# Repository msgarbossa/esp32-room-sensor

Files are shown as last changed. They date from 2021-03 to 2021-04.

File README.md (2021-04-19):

# ESP32 room temp sensor

## Overview

This ESP32 sensor is setup to wake from deep sleep every 5 minutes, take a sensor reading, send the data to MQTT, and go back to sleep.  Intended for dark rooms, the OLED is only activated for about 10 seconds by tapping the touch sensor on the top.  The number in the lower-right corner is the signal strength.  Update settings in src/config/config.h.

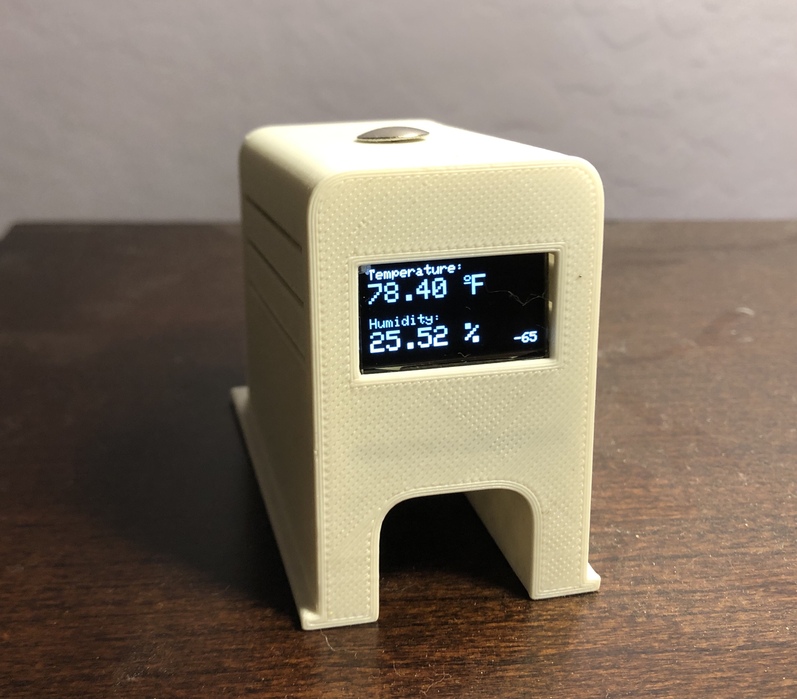
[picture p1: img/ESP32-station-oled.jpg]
project photo


I resized this case to fit the parts I like to use.  The screen is currently just glued in with hot glue.

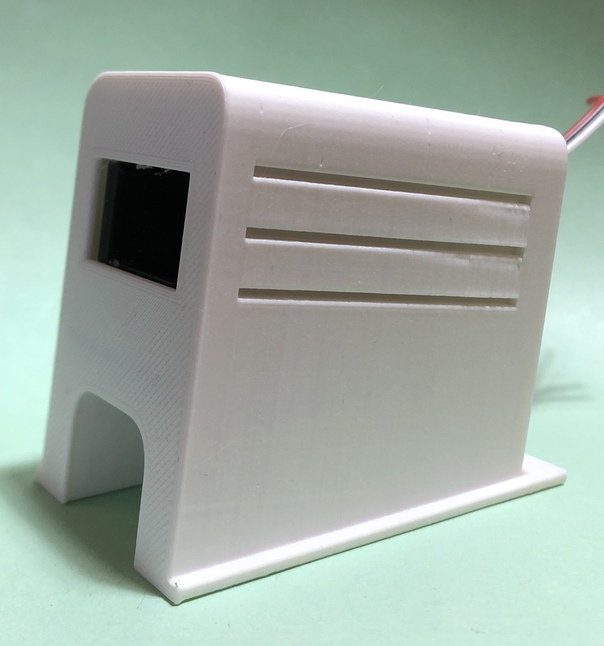
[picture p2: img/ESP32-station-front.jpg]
front


The 30-pin ESP32 board with integrated antenna slides perfectly into the rail.

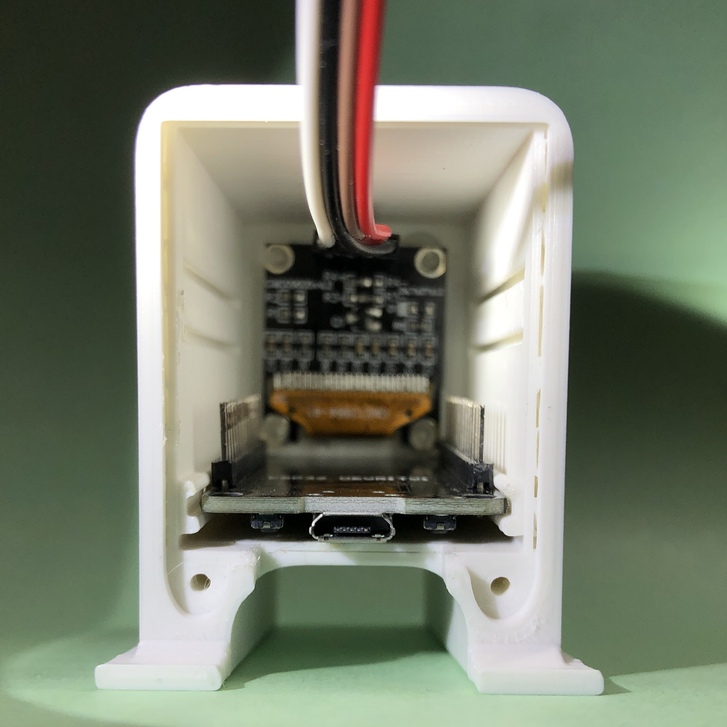
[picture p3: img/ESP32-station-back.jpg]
back


The cover hooks into the top edge and the bottom can stay pressed in.  I didn't need to add screws.  I modified the cover with a small cutout at the top so the BME280 sensor can be external.  I'd like to further tweak the cover to better hold the sensor.

## Parts

- [ESP32 devkit - 30 pin, integrated antenna](https://www.aliexpress.com/item/1005001267643044.html)
- [0.96" OLED - white, I2C](https://www.aliexpress.com/item/32896971385.html)
- [BME280 sensor](https://www.aliexpress.com/item/4001098967210.html)

## Diagram

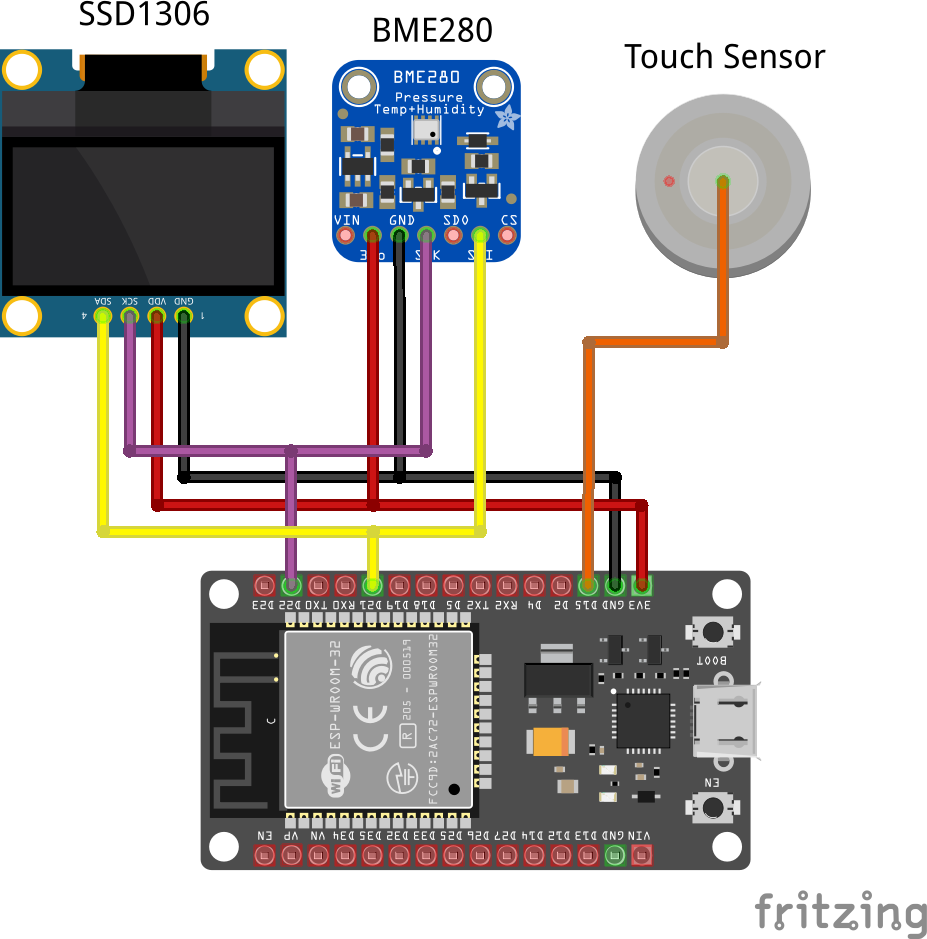
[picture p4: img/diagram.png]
diagram


## Node-RED

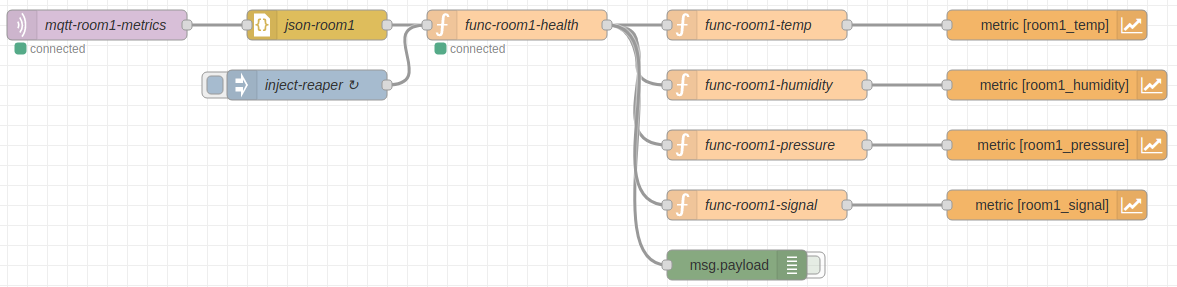
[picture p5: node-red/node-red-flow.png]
Node-RED flow

[JSON for above flow](node-red/flow.json)

The beginning of the flow starts out very simple.  Node-RED listens on the MQTT topic for the sensor.  The messages get converted from JSON to payload objects.

To understand the rest of the flow, it's important to go over how the Prometheus node exporter works in Node-RED.  The orange metric boxes to the right-side of the flow generate the prometheus data shown below at \<node_red_url\>:1880/metrics.

```
# HELP room1_temp room1 temp
# TYPE room1_temp gauge
room1_temp 78

# HELP room1_humidity room1 humidity
# TYPE room1_humidity gauge
room1_humidity 31.32

# HELP room1_pressure room1 pressure
# TYPE room1_pressure gauge
room1_pressure 964.77

# HELP room1_signal room1 signal
# TYPE room1_signal gauge
room1_signal -70
```

The challenge has been dealing with sensors that go offline.  The metric node would not receive an updated value and continue to display an old value.  This would show up in the graphs in Grafana as a flat-line.  There might be a more elegant solution, but what I've done for now is to use an inject node to regularly inject a healthcheck message into the flow.  The healthcheck function node uses node context to store the time of the last valid message that came from MQTT.  When the healthcheck message is injected, the time of the inject message is compared to the time of the last valid message.  If the time difference is greater than the threshold, the healthcheck node's status is set to "offline" and a new message is generated and passed along with the metric values set to zero.  The Grafana graphs are set to only display values greater than zero.

The functions to the left of each of the orange metric nodes simply reformat the payload messages to set the metric values as required for the Promtheus metric nodes.

Below is an example graph in Grafana.

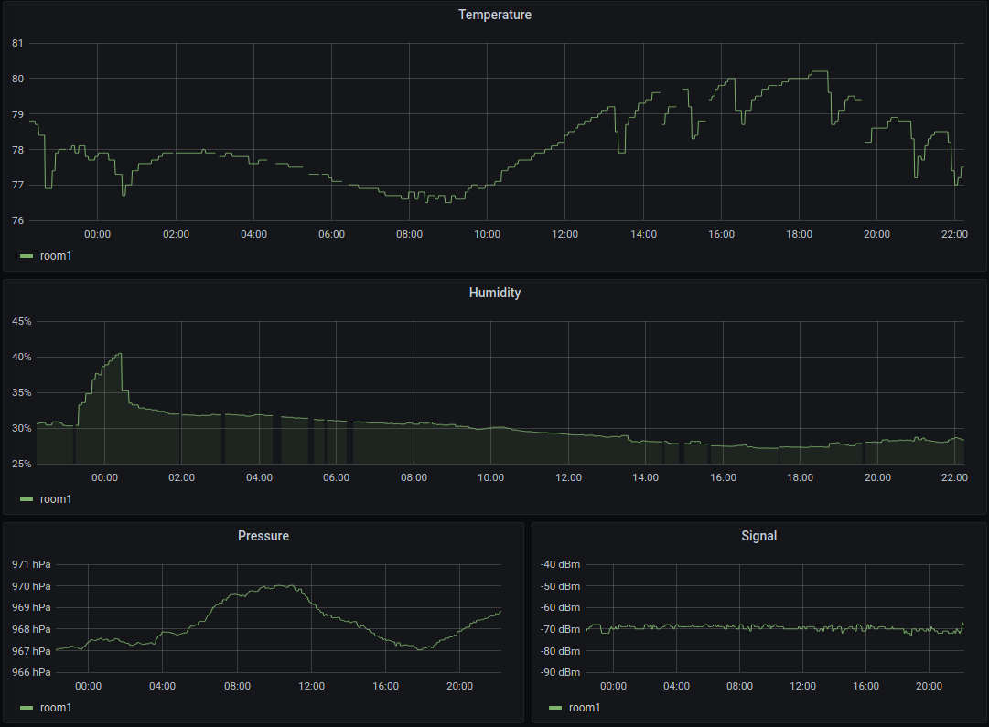
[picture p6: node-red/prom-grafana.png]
Prometheus - Grafana


## Over the Air (OTA) Updates

OTA updates seem more commonly used with sensors that do not utilize deep sleep.  To get OTA updates to work and minimize the wake time, the bootcount variable is used with RTC_DATA_ATTR to maintain the number of times the ESP32 wakes from sleep after being powered on.  The OTA update is only checked the first time the ESP32 is powered on.  The OTA update process works the same is it normally would except that the ESP32 needs a hard restart to reset the counter to zero and check for the update.  The IP address of the ESP32 needs to be updated in platform.ini file and the upload_port entry for USB needs to be commented out.

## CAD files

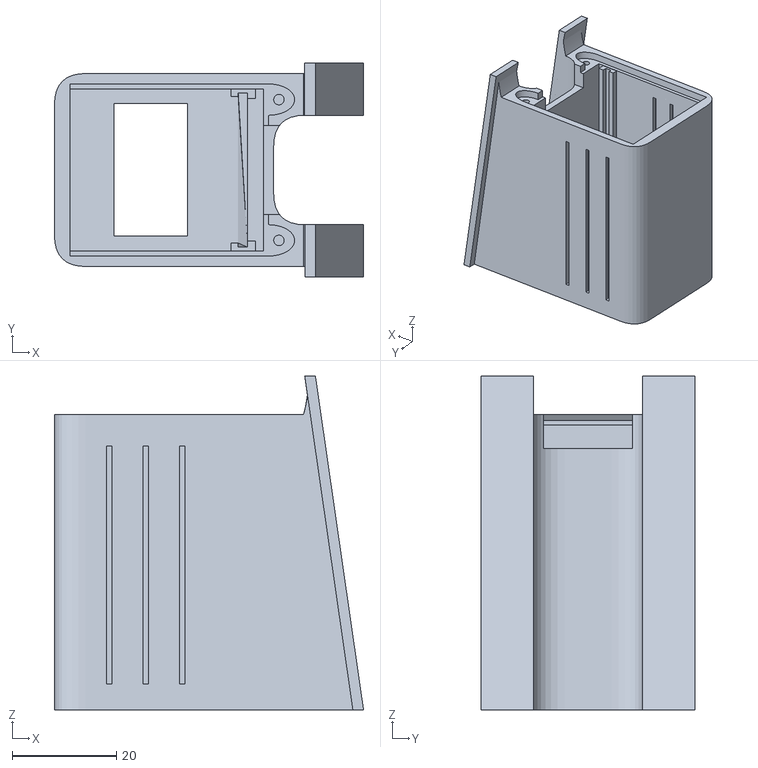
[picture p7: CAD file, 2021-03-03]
3d-printed-case/case.stl
59.2 x 41.0 x 64.0

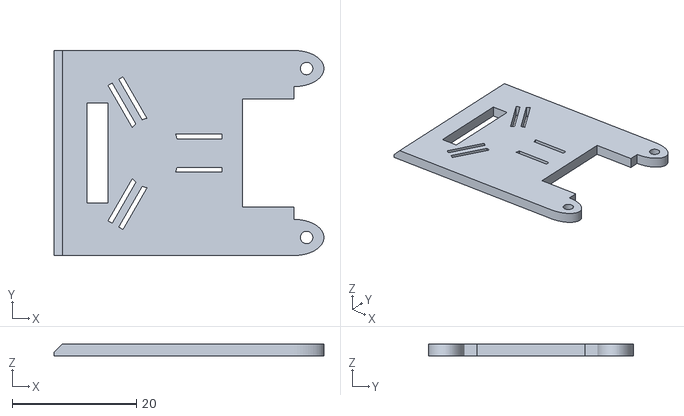
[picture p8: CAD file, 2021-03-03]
3d-printed-case/cover.stl
43.4 x 33.0 x 2.00

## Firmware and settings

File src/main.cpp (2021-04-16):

#include <Arduino.h>
#include <WiFi.h>
#include <SPI.h>
#include <Wire.h>
#include <Adafruit_GFX.h>
#include <Adafruit_SSD1306.h>

#include "config/config.h"
#include "functions/wifi-connection.h"
#include "functions/ota.h"
#include "functions/deep-sleep.h"
#include "functions/temp-bme280.h"
#include "functions/mqtt.h"

#ifdef __arm__
// should use uinstd.h to define sbrk but Due causes a conflict
extern "C" char* sbrk(int incr);
#else  // __ARM__
extern char *__brkval;
#endif  // __arm__

#define SCREEN_WIDTH 128 // OLED display width, in pixels
#define SCREEN_HEIGHT 64 // OLED display height, in pixels

// Declaration for an SSD1306 display connected to I2C (SDA, SCL pins)
#define OLED_RESET     -1 // Reset pin # (or -1 if sharing Arduino reset pin)
Adafruit_SSD1306 display(SCREEN_WIDTH, SCREEN_HEIGHT, &Wire, OLED_RESET);

RTC_DATA_ATTR int bootCount = 0;
float temp;
float humidity;
float pressure;
int8_t wifi_strength;

esp_sleep_wakeup_cause_t wakeup_reason;

#define I2C_SDA 21
#define I2C_SCL 22

void updateWiFiSignalStrength() {
  if(WiFi.isConnected()) {
    //serial_println(F("[WIFI] Updating signal strength..."));
    wifi_strength = WiFi.RSSI();
    Serial.print("[WIFI] signal strength: ");
    Serial.println(wifi_strength);
  }
}

void displayStats() {
  // clear display
  display.clearDisplay();
  display.setTextColor(WHITE);
  
  // display temperature
  display.setTextSize(1);
  display.setCursor(0,0);
  display.print("Temperature: ");
  display.setTextSize(2);
  display.setCursor(0,10);
  display.print(temp);
  display.print(" ");
  display.setTextSize(1);
  display.cp437(true);
  display.write(167);
  display.setTextSize(2);
  display.print("F");
  
  // display humidity
  display.setTextSize(1);
  display.setCursor(0, 35);
  display.print("Humidity: ");
  display.setTextSize(2);
  display.setCursor(0, 45);
  display.print(humidity);
  display.print(" %");

  // display wifi signal strength
  display.setTextSize(1);
  display.setCursor(110, 56);
  display.print(String(wifi_strength));
  
  display.display();
  delay(1000); // Pause for 1 second
}

void callback(){
  //placeholder callback function
  Serial.println("Touchpad activated, do some work...");
}

void setup() {

  Serial.begin(115200);

  //Increment boot number and print it every reboot
  ++bootCount;
  Serial.println("Boot number: " + String(bootCount));

  setup_sleep();
  Wire.begin(I2C_SDA, I2C_SCL);

  setupTemp();
  measureTemp();

  // Display stats waking up from touch sensor
  if (wakeup_reason == 5) {
    // SSD1306_SWITCHCAPVCC = generate display voltage from 3.3V internally
    if(!display.begin(SSD1306_SWITCHCAPVCC, 0x3C)) { 
      Serial.println(F("SSD1306 allocation failed"));
      for(;;); // Don't proceed, loop forever
    }
    displayStats();
  }

  connectWiFi();
  updateWiFiSignalStrength();
  mqttConnect();
  sendTempToMQTT();
  mqttDisconnect();

  // When wakeing up from sensor, update stats to show wifi strength.
  // Then pause long enough for stats to be read.
  if (wakeup_reason == 5) {
    displayStats();
    delay(7000); // Pause for 10 second
    display.clearDisplay();
    display.display();
  }

  // Setup interrupt on Touch Pad 3 (GPIO15)
  touchAttachInterrupt(T3, callback, Threshold);

  // Configure Touchpad as wakeup source
  esp_sleep_enable_touchpad_wakeup();

  // Check OTA update on first boot
  if (bootCount == 1) {
    setupOTA();
    delay(2000);
    // takes a few attempts.  worked on count=11 (2s each)
    unsigned short maxRetry = 20;
    unsigned short countRetry = 0;
    while(countRetry <= maxRetry) {
        Serial.println("[OTA] count: " + String(countRetry));
        countRetry++;
        ArduinoOTA.handle();
        delay(2000);
    }
  }

  deep_sleep();
}

void loop() {
}
